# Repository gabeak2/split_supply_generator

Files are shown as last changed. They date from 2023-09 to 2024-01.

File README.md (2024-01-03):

# split_supply_generator
A SMPS board to generate a +/-15V rail from 5V USB or 9-12V Barrel jack.  Uses switching regulators followed by linear ones, so noise performance is pretty good at ~1mVpp!


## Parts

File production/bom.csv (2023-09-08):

Designator | Footprint | Quantity | Value | LCSC Part #
C1, C13, C15, C18, C22, C5, C7, C9 | C_0805_2012Metric | 8 | 100n
C10, C11, C14, C16, C17, C19, C2, C20, C21, C23, C3, C4, C6, C8 | C_0805_2012Metric | 14 | 10u
C12, C24 | C_0805_2012Metric | 2 | 1.5nF
D1, D2, D3, D4, D5, D6 | D_SOD-123 | 6 | D_Schottky_Small
FB1, FB2 | L_0805_2012Metric | 2 | FerriteBead_Small
H1, H2, H3, H4 | MountingHole_2.2mm_M2_DIN965_Pad | 4 | MountingHole_Pad
J1 | BarrelJack_GCT_DCJ200-10-A_Horizontal | 1 | Barrel_Jack_Switch
J2 | PinSocket_1x03_P2.54mm_Vertical | 1 | Conn_01x03
J3 | USB_Micro-B_Molex-105017-0001 | 1 | USB_B_Micro
J4 | PinSocket_1x02_P2.54mm_Vertical | 1 | Conn_01x02
L1, L2 | ind_SWRB1207S-221MT | 2 | 220u
R1, R11, R12, R13, R14, R2, R3, R4 | R_0805_2012Metric | 8 | 1
R10, R15, R7 | R_0805_2012Metric | 3 | 1k
R16, R9 | R_0805_2012Metric | 2 | 100
R17, R6 | R_0805_2012Metric | 2 | 15k
R5 | R_0805_2012Metric | 1 | 180
R8 | R_0805_2012Metric | 1 | 11k
U1, U3 | SOIC-8_3.9x4.9mm_P1.27mm | 2 | MC34063AD
U2 | TO-252-2 | 1 | LM317_TO-252
U4 | TO-263-2 | 1 | MC7915

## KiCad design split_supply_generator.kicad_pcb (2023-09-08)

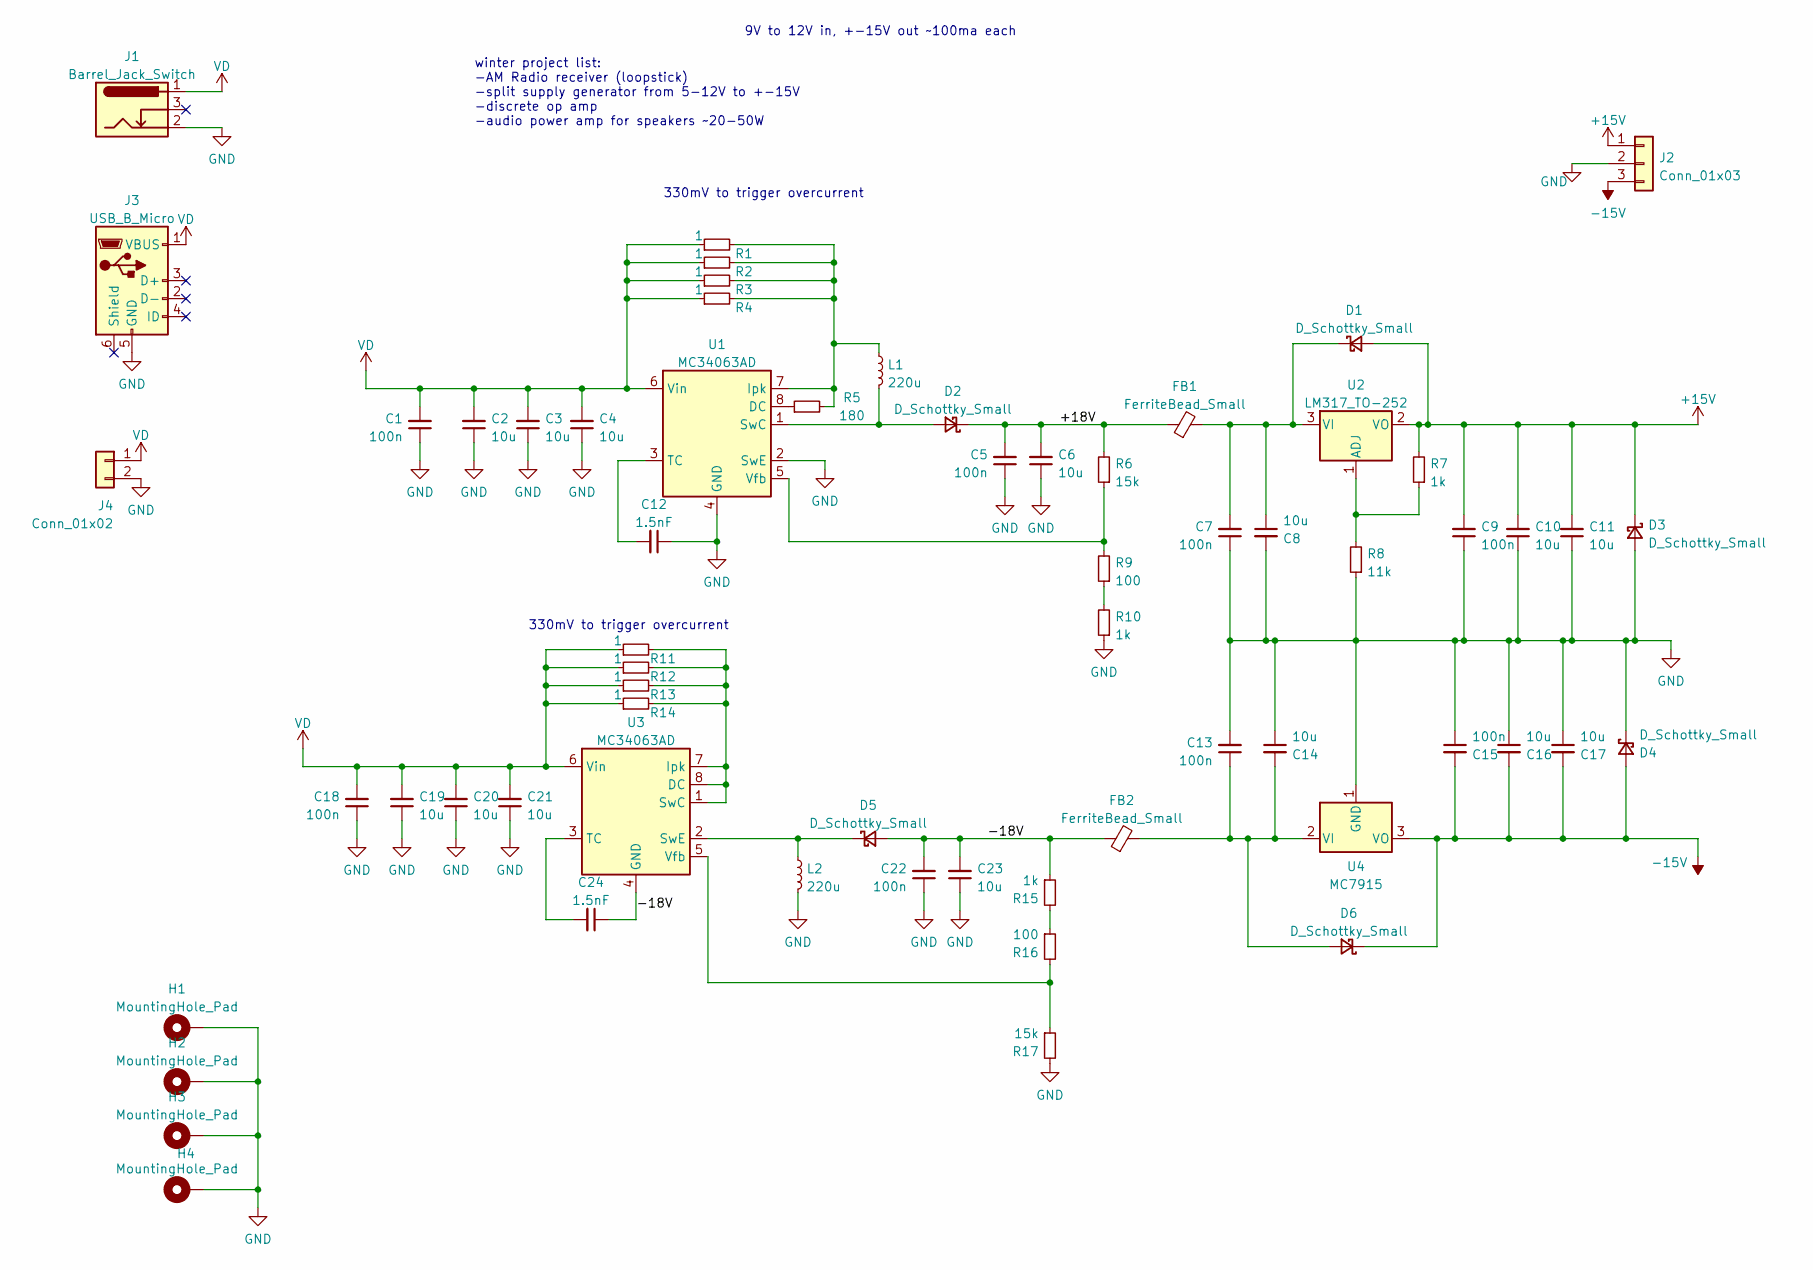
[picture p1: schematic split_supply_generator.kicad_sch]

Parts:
C1, C5, C7, C9, C13, C15, C18, C22: 100n; C_0805_2012Metric; LCSC PN C49678
C2, C3, C4, C6, C8, C10, C11, C14, C16, C17, C19, C20, C21, C23: 10u; C_0805_2012Metric; LCSC PN C440198
C12, C24: 1.5nF; C_0805_2012Metric; LCSC PN C1717
D1, D2, D3, D4, D5, D6: D_Schottky_Small; D_SOD-123; LCSC PN C8598
FB1, FB2: FerriteBead_Small; L_0805_2012Metric; LCSC PN C1017
H1, H2, H3, H4: MountingHole_Pad; MountingHole_2.2mm_M2_DIN965_Pad
J1: Barrel_Jack_Switch; BarrelJack_GCT_DCJ200-10-A_Horizontal
J2: Conn_01x03; PinSocket_1x03_P2.54mm_Vertical
J3: USB_B_Micro; USB_Micro-B_Molex-105017-0001
J4: Conn_01x02; PinSocket_1x02_P2.54mm_Vertical
L1, L2: 220u; ind_SWRB1207S-221MT; LCSC PN C169380
R1, R2, R3, R4, R11, R12, R13, R14: 1; R_0805_2012Metric; LCSC PN C25271
R5: 180; R_0805_2012Metric; LCSC PN C25270
R6, R17: 15k; R_0805_2012Metric; LCSC PN C17475
R7, R10, R15: 1k; R_0805_2012Metric; LCSC PN C17513
R8: 11k; R_0805_2012Metric; LCSC PN C17429
R9, R16: 100; R_0805_2012Metric; LCSC PN C17408
U1, U3: MC34063AD; SOIC-8_3.9x4.9mm_P1.27mm; LCSC PN C32078
U2: LM317_TO-252; TO-252-2
U4: MC7915; TO-263-2

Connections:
+15V: C9.2, C10.2, C11.2, D1.2 (A), D3.1 (K), J2.1, R7.2, U2.2 (VO)
-15V: C15.2, C16.2, C17.2, D4.2 (A), D6.1 (K), J2.3, U4.3 (VO)
/+18V: C5.2, C6.2, D2.1 (K), FB1.1, R6.2
/-18V: C22.2, C23.2, C24.1, D5.2 (A), FB2.1, R15.1, U3.4 (GND)
GND: C1.1, C2.1, C3.1, C4.1, C5.1, C6.1, C7.1, C8.2, C9.1, C10.1, C11.1, C12.1, C13.2, C14.1, C15.1, C16.1, C17.1, C18.1, C19.1, C20.1, C21.1, C22.1, C23.1, D3.2 (A), D4.1 (K), H1.1, H2.1, H3.1, H4.1, J1.2, J2.2, J3.5 (GND), J4.2, L2.2, R8.1, R10.1, R17.2, U1.2 (SwE), U1.4 (GND), U4.1 (GND)
unnamed: C7.2, C8.1, D1.1 (K), FB1.2, U2.3 (VI)
unnamed: C12.2, U1.3 (TC)
unnamed: C13.1, C14.2, D6.2 (A), FB2.2, U4.2 (VI)
unnamed: C24.2, U3.3 (TC)
unnamed: D2.2 (A), L1.2, U1.1 (SwC)
unnamed: D5.1 (K), L2.1, U3.2 (SwE)
unnamed: L1.1, R1.2, R2.2, R3.2, R4.2, R5.2, U1.7 (Ipk)
unnamed: R5.1, U1.8 (DC)
unnamed: R6.1, R9.2, U1.5 (Vfb)
unnamed: R7.1, R8.2, U2.1 (ADJ)
unnamed: R9.1, R10.2
unnamed: R11.2, R12.2, R13.2, R14.2, U3.1 (SwC), U3.7 (Ipk), U3.8 (DC)
unnamed: R15.2, R16.1
unnamed: R16.2, R17.1, U3.5 (Vfb)
VD: C1.2, C2.2, C3.2, C4.2, C18.2, C19.2, C20.2, C21.2, J1.1, J3.1 (VBUS), J4.1, R1.1, R2.1, R3.1, R4.1, R11.1, R12.1, R13.1, R14.1, U1.6 (Vin), U3.6 (Vin)

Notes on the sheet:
9V to 12V in, +-15V out ~100ma each
winter project list: -AM Radio receiver (loopstick) -split supply generator from 5-12V to +-15V -discrete op amp -audio power amp for speakers ~20-50W
330mV to trigger overcurrent

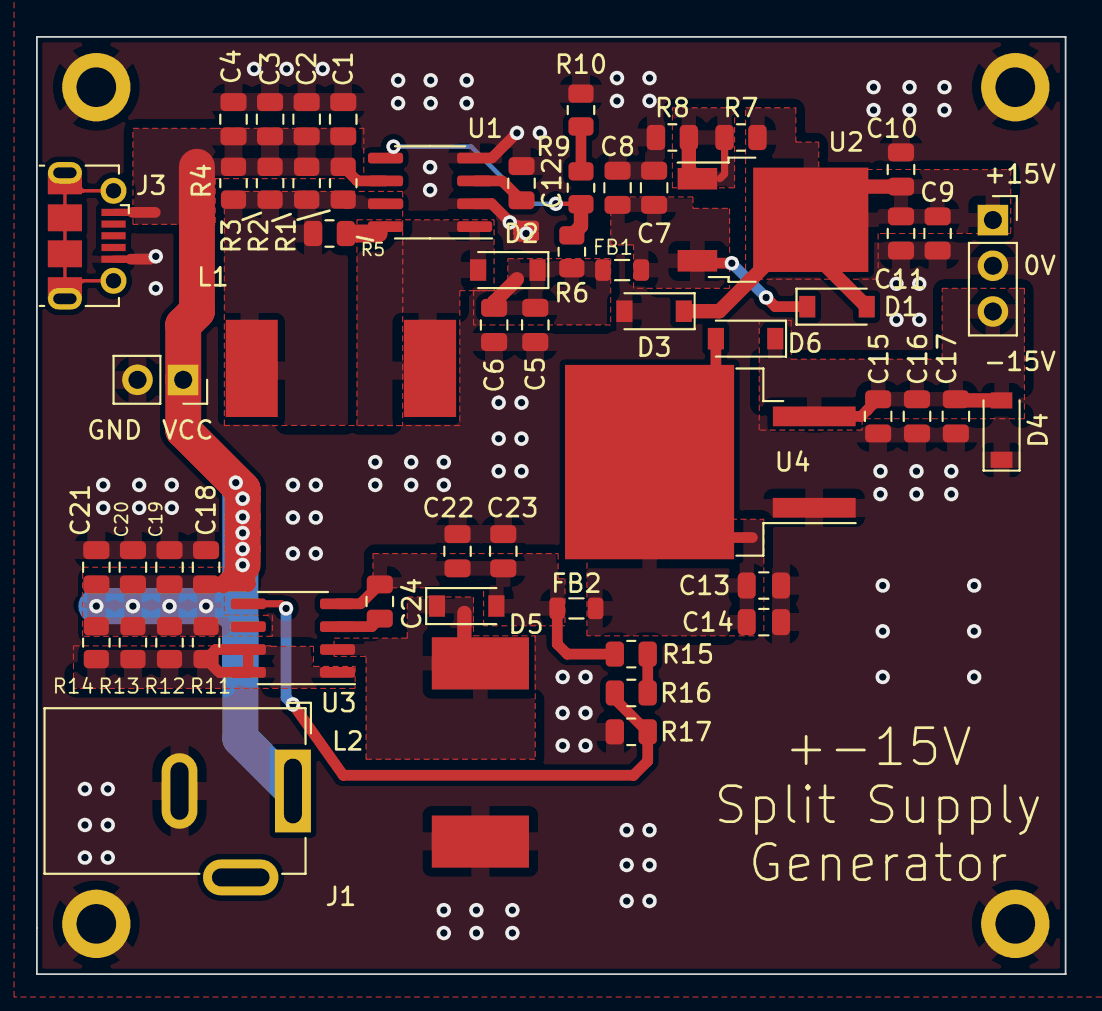
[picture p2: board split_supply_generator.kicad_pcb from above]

Board: 2 copper layers, 57.1 x 52.1 mm, 63 parts (0 on the bottom side), 20 nets.
